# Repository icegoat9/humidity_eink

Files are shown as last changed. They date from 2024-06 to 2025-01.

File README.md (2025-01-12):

## Humidity Monitor: Feather + E Ink

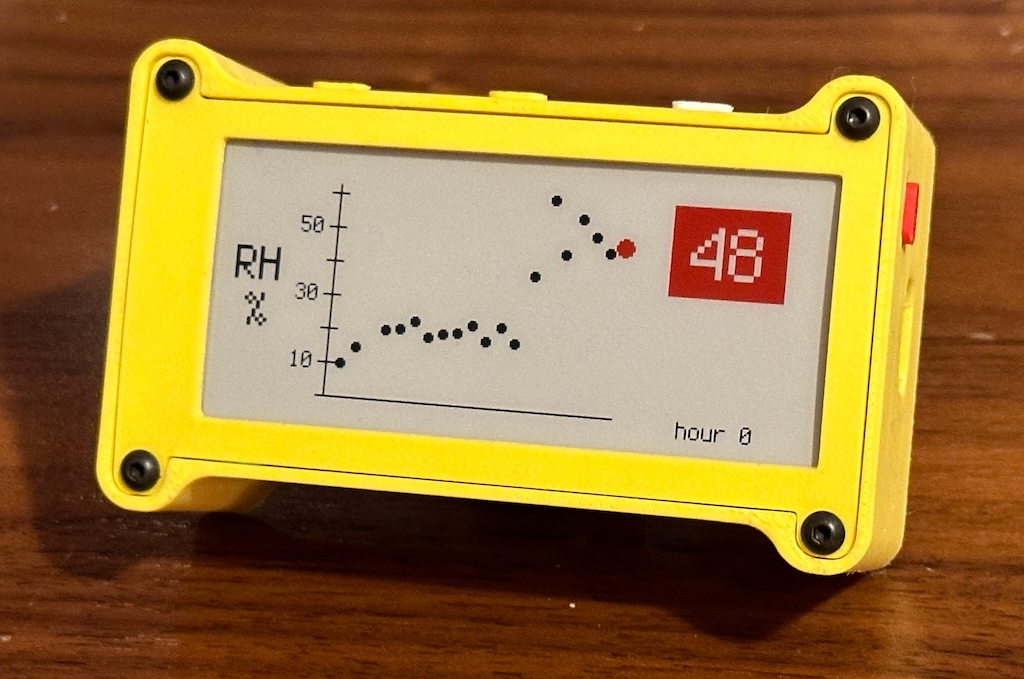
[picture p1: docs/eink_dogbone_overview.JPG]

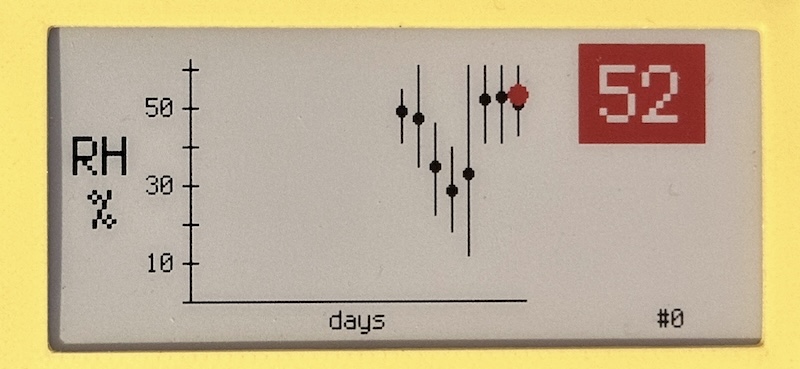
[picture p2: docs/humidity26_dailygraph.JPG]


## Overview

A humidity monitor and logger, using an E Ink display to show the recent and historical humidity with almost zero power draw (the embedded system stays in sleep mode, just waking up once an hour to read a sensor and update the display).

This was a very quick project (3 evenings, ~12 hours not counting this writeup). 

## Background

I recently picked up a 3D printer for my 'home lab', partly to make it faster to build cases for various electronics projects I work on.

I plan to store my extra printer filament in a dry box with desiccant, and wanted to throw a humidity monitor into the box-- instead of buying one, maybe I should make one (and this would be an excuse to try quick iterations on case design).

I had other projects to work on, so I told myself "If I can build a working prototype in one evening with parts I have around, I'll let myself spend a few more days polishing it."

I rarely document one-off projects like this, but I thought it would be useful/fun for when I look back at it in the future, so I took photos and screenshots along the way to let me reconstruct the process after the fact.

## Development Log

### Day 1 -- Working Prototype

Notebook sketch concept:
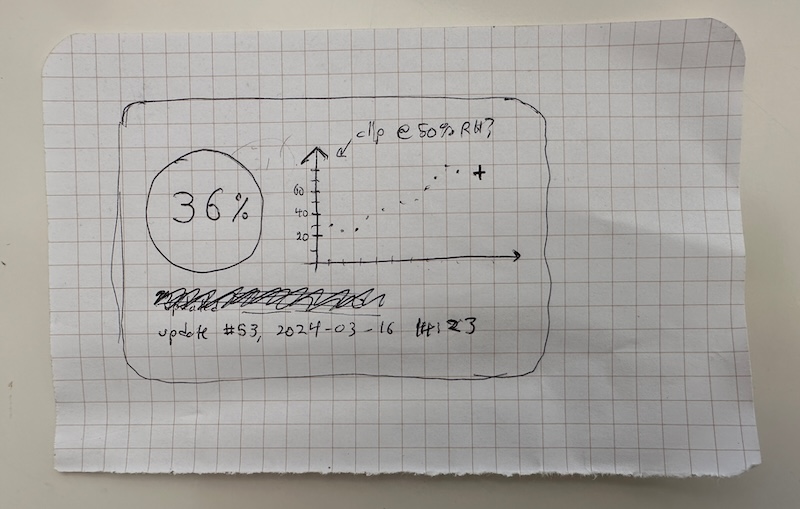
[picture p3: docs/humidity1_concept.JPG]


Components I had kicking around the shop, including a [Feather M4 Express](https://www.adafruit.com/product/3857) with a 120 Mhz Cortex M4 SAMD51 processor, a [2.9" Tri-color E Ink display](https://www.adafruit.com/product/4778), and an [AHT20 I2C capacitive humidity sensor](http://www.aosong.com/en/products-32.html) on a [breakout board](https://www.adafruit.com/product/4566):
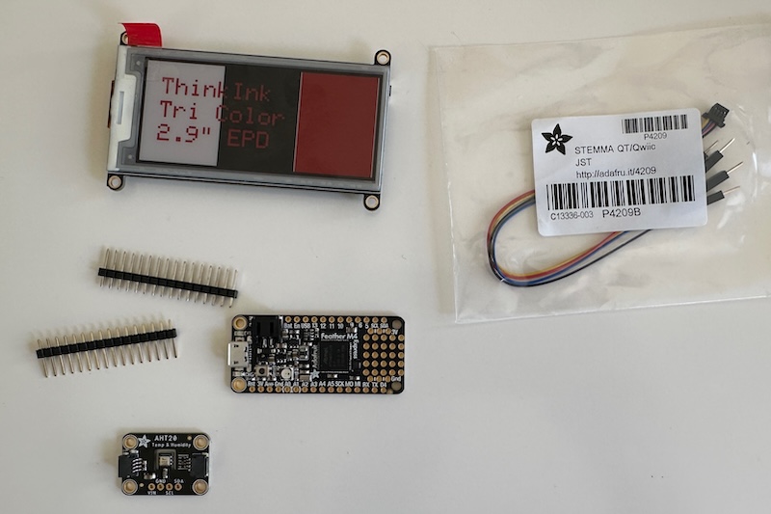
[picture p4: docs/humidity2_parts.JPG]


First I soldered headers onto the Feather PCB (tip: insert the headers into the mating display board while soldering to keep them aligned):
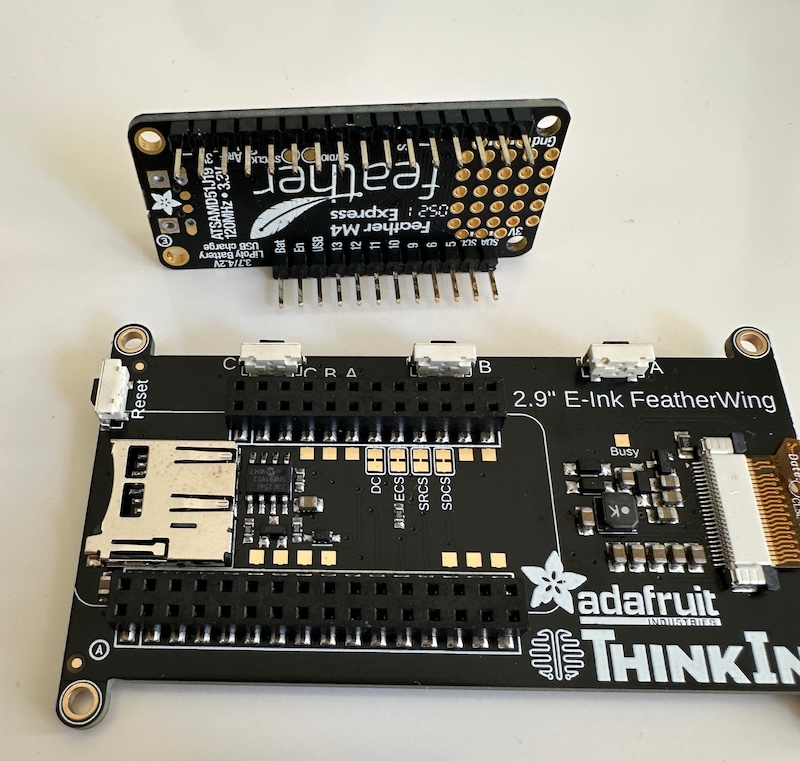
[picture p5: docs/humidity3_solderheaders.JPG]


Then I hooked up the relevant I2C bus pins to the sensor:
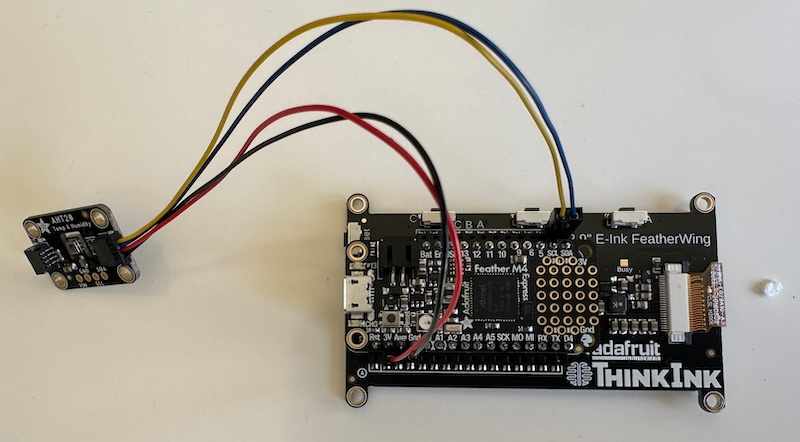
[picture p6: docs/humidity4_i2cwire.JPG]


I connected the Feather to my laptop to update the firmware and start programming, but wasn't able to communicate with it. I wasted more minutes than I want to admit before I figured out the USB cable I'd grabbed was a charging-only cable with no data connection.
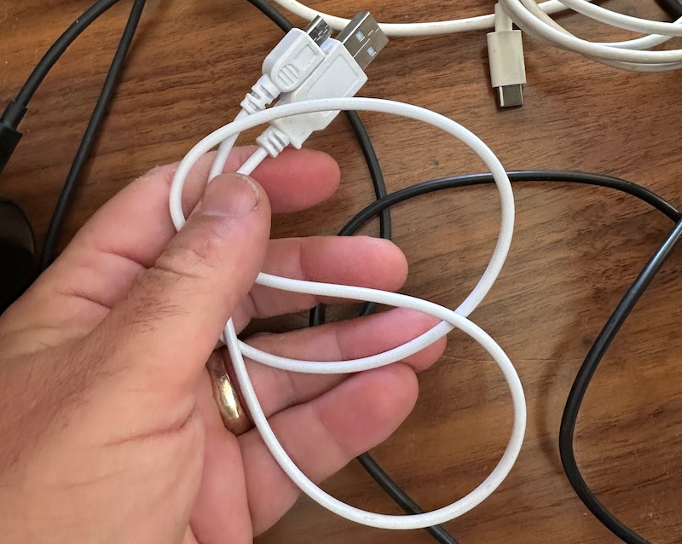
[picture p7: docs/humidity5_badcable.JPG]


Now I was able to load CircuitPython onto the device. I always start with some basic 'blink an LED' code to check my workflow:
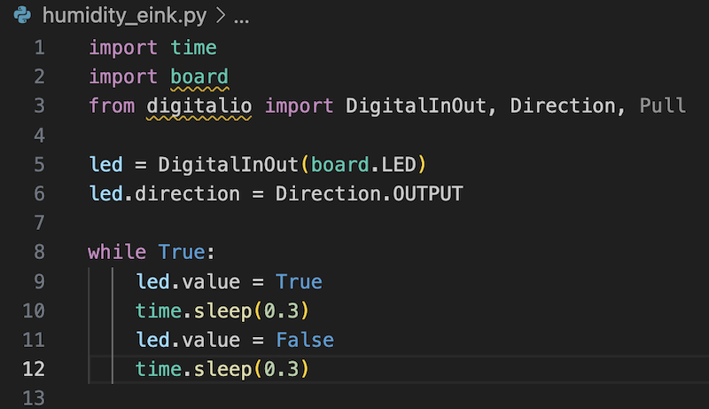
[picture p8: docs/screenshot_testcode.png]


Next, I loaded some sample code from [Adafruit's excellent-as-always documentation](https://learn.adafruit.com/adafruit-2-9-eink-display-breakouts-and-featherwings/overview), verifying I could display an image on the E Ink`.

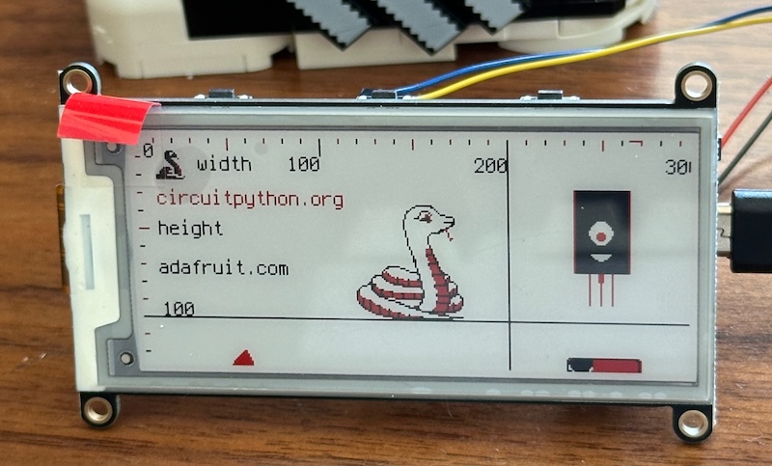
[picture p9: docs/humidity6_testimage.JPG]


I brushed up on the [`displayio`](https://docs.circuitpython.org/en/latest/shared-bindings/displayio/) library which I've used in the past to composite elements into an image and wrote a few lines of code. Oops, I forgot that (x,y) coordinates in displayio anchor by default to the vertical center of text:
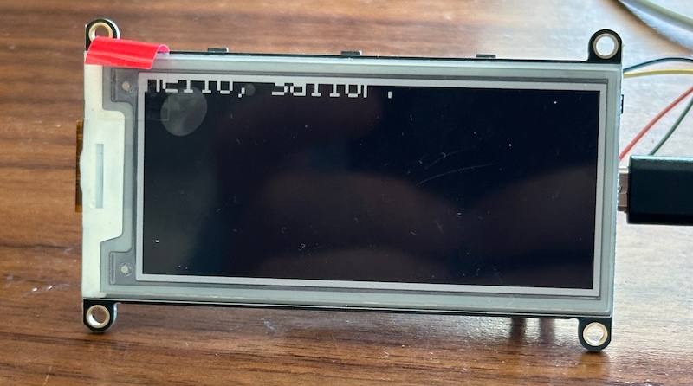
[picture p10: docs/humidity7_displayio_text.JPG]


Fixed:
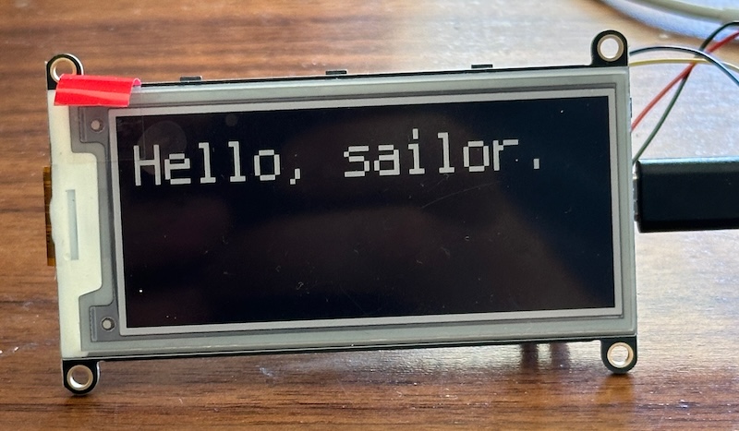
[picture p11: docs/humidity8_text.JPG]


For simple projects like this, I'm a big fan of 'printf debugging'-- just printing program status out to a serial terminal for quick feedback. I connected a terminal window to the Feather's serial-over-USB connection:
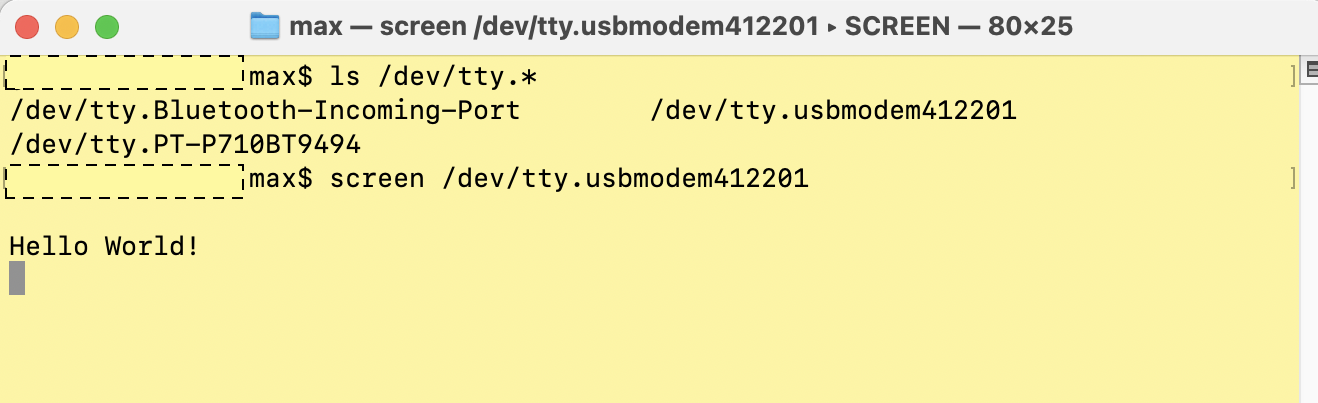
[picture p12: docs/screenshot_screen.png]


Now I wanted to communicate to the humidity sensor over I2C. One of the features of Python I love is the easy REPL / shell, allowing interactive command exploration. I read the documentation and tried out a few commands, and was able to communicate to the sensor, verifying it works the way I think and I have it wired up correctly:
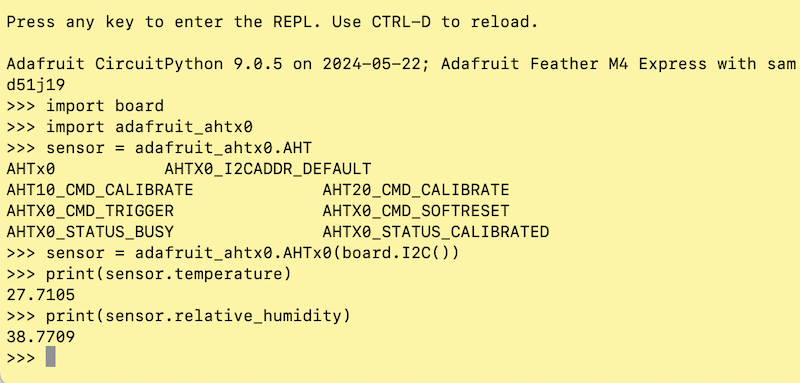
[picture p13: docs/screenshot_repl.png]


Now that I know it works, I integrated I2C code into my basic test program and displayed it:
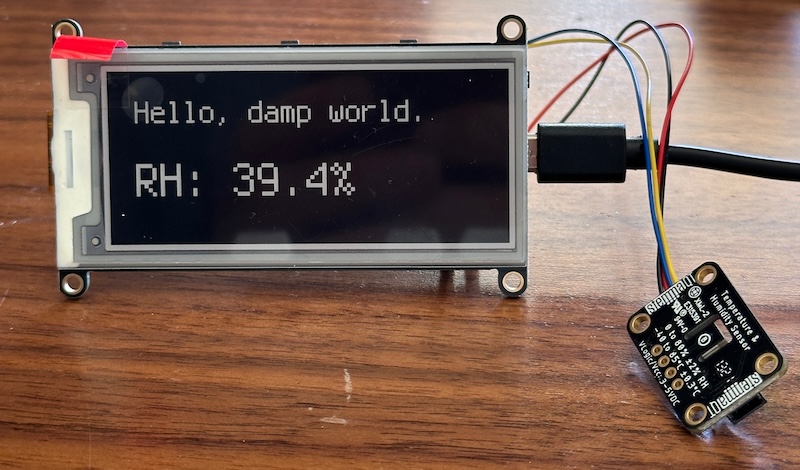
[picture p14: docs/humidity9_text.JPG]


This moment was about an hour and a half from when I had the idea and started this project. It's a key prototype milestone-- now that I know it's possible with components I have on hand, I'm excited to spend some more time on it.

I took a break to set up a git repository, back up my work in progress, and arrange my monitor windows the way I like them for more focused work. 
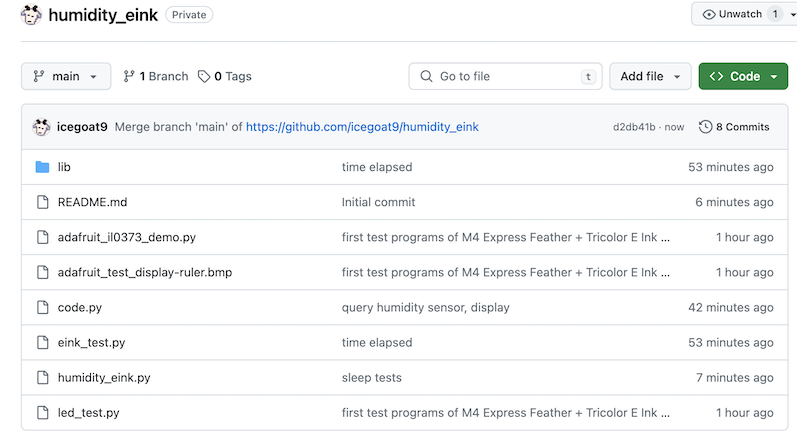
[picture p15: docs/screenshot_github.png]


Now let's dive back in.

I played around with color and formatting settings for this display (I'm only using this much slower three-color E Ink display instead of a black and white one because it's what I had on hand... but since I have it I might as well use the accent color):
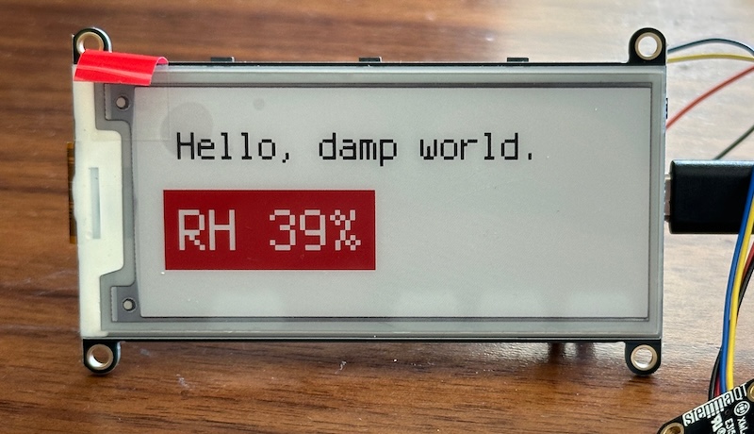
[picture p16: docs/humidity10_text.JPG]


Now I swapped in a small LiPoly battery instead of USB power, since the intent is to make this battery-powered:
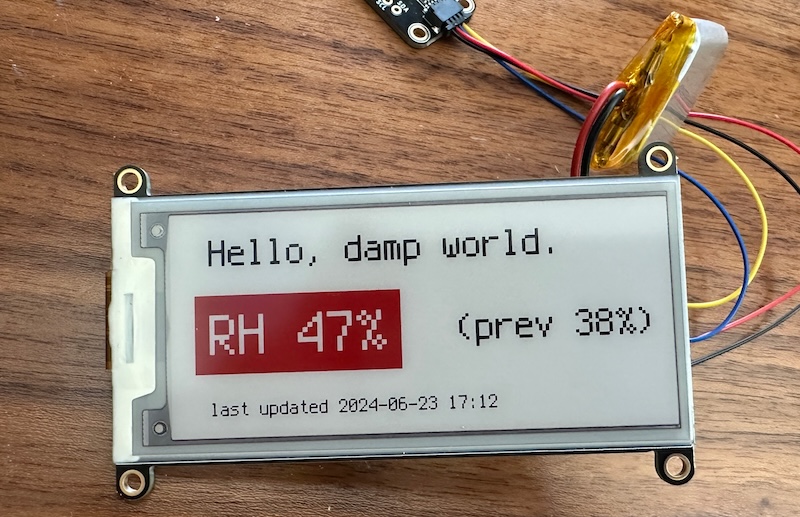
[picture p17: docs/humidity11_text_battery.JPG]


I spent a bit of time brushing up on low-power sleep modes using [`alarm.sleep`](https://learn.adafruit.com/deep-sleep-with-circuitpython/alarms-and-sleep) and wrote some test code to check I could have the system sleep and then wake itself up on some schedule. The onboard RTC time and date don't seem to persist across a sleep/wake the way I'm using it, but I don't really need an accurate time so I'll ignore that for now:
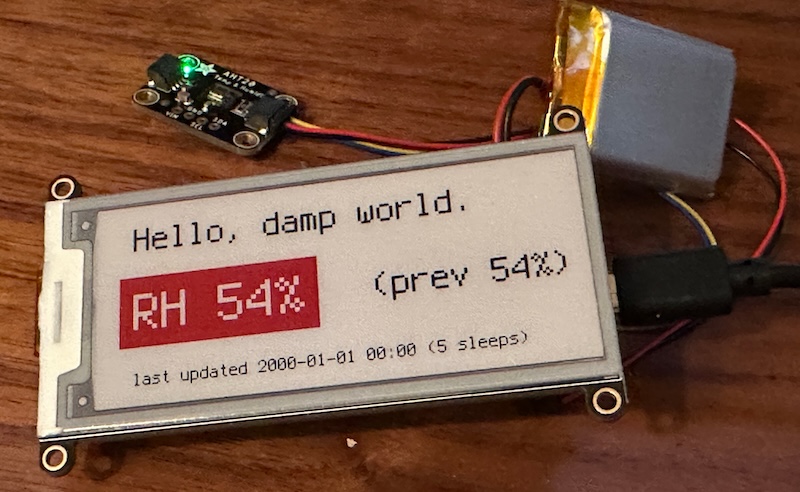
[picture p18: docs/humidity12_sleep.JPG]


There's more to do on making this look good, but let's make a case for all these loose components and wires. I'm fortunate to have a small 3D printer in my home lab, and using the PCB documentation as a starting point, in a bit over an hour I had a basic case designed and printed (about 40 minute print time with coarse draft settings):

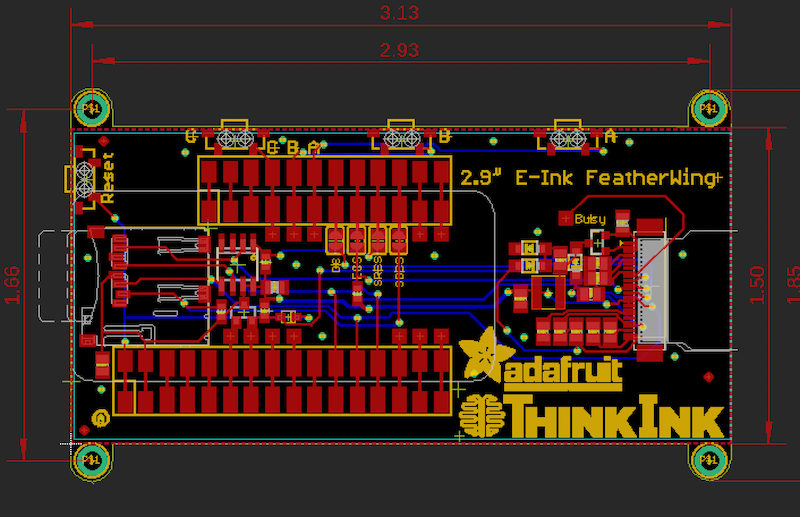
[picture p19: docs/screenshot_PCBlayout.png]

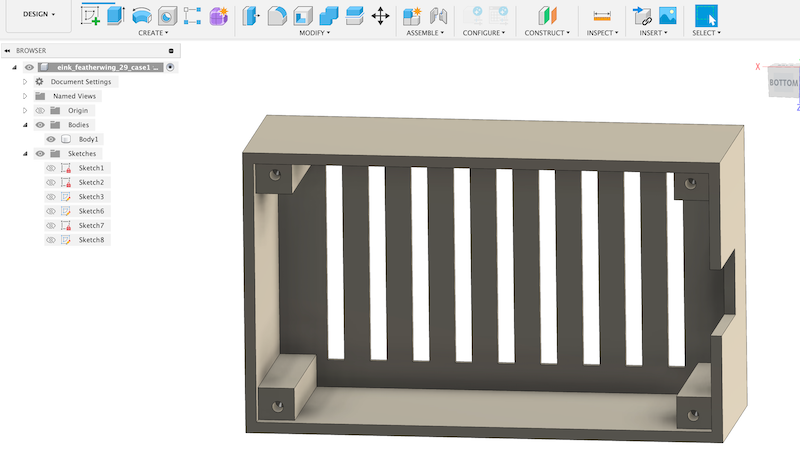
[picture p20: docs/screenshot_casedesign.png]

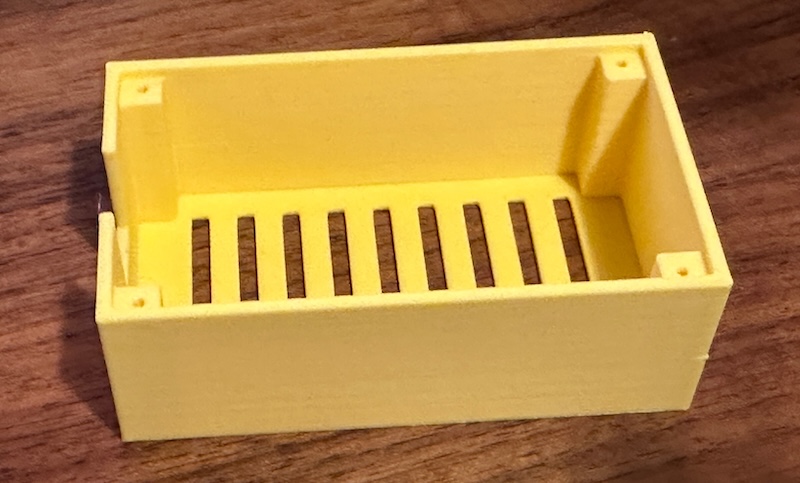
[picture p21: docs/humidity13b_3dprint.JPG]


The enclosure didn't fit perfectly (I needed slightly more PCB clearance in a few areas, but when it's this fast to design / build / test, I don't spend as much time trying to get every dimension perfect on the first try), but it worked well enough that I could dry fit the components in to it and set it inside my storage bin to imagine what it would look like:
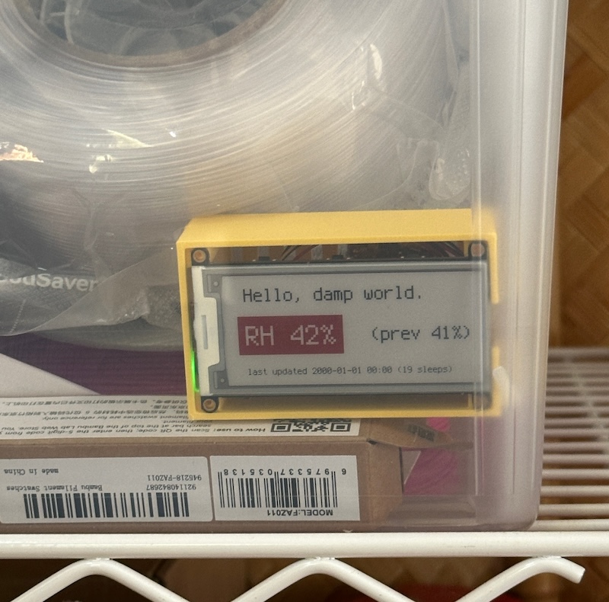
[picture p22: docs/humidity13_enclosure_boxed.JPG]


I set the system to wake up once an hour, update the display, and return to low-power sleep mode, and this is where I left it after my first evening on the project. Actually, I also fixed a few minor fit issues on the case design and set it to 3D print overnight. 

## Day 2

To some extent, this rough prototype is already 'good enough'-- I can see the humidity inside the box. But I wanted to put a few more hours of polish into it.

I went through a few more iterations of case design, fixing fit issues and adding mounting holes for the sensor.

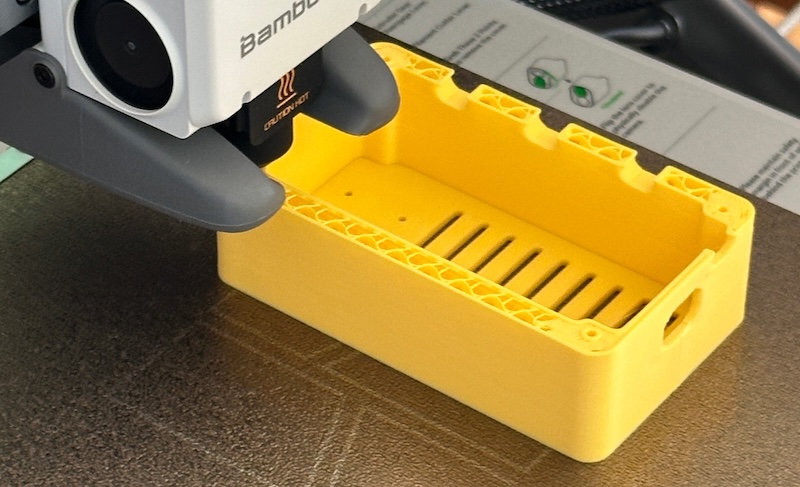
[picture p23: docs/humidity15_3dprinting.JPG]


A robust design might heat-set threaded metal inserts into the case for strong screw connections, or design in some plastic snap tabs, but for this kind of quick project I find I can usually tap threads directly into the 3D printed plastic if I'm careful and only going to open and close it a few times ever (in the 3D printer slicer I need to remember to set infill density to 100% in those areas or for the whole part, so there's material to bite into, not just a thin wall):

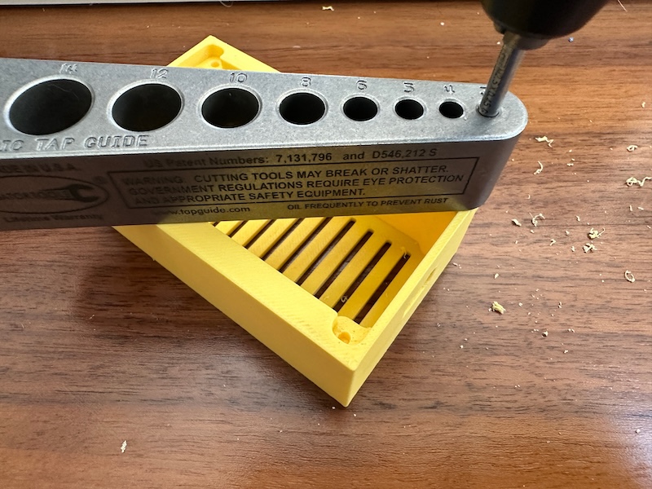
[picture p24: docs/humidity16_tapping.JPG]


Also, since I have all this display space, maybe I could do something more interesting than just print text, such as keep an internal log of humidity over time and graph it.

I tested the CircuitPython [`display_shapes`](https://docs.circuitpython.org/projects/display-shapes/en/latest/) sparkline module, but didn't love how it looked:

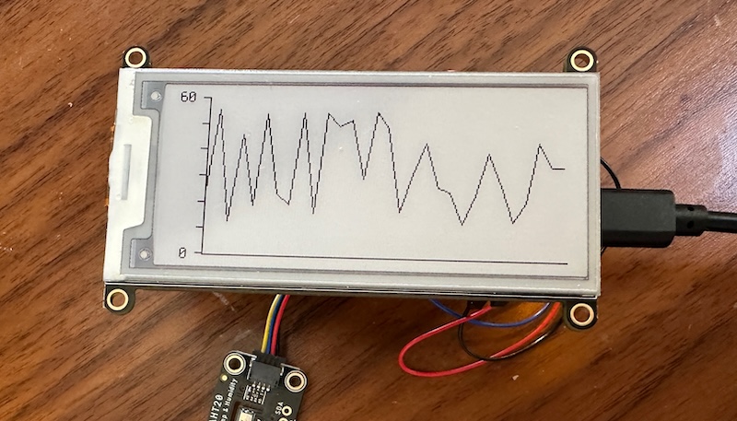
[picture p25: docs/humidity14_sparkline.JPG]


I decided to make my own chart drawing routine, using the line and circle primitives from `display_shapes`. To iterate quickly on ideas, I wrote some throwaway code using some hard-coded dummy data that just draws a set graph to the screen. After playing around with some math and settings for a while, I came up with this layout, which I liked:

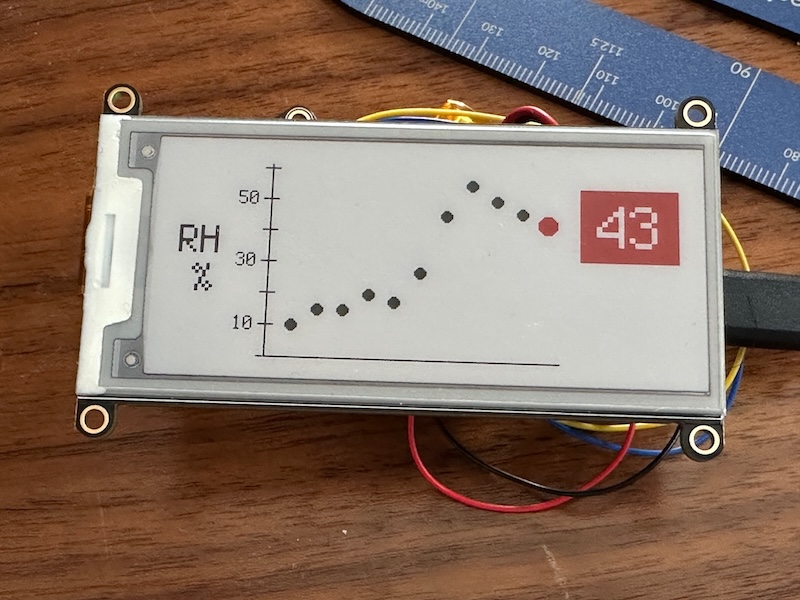
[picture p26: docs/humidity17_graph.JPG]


This was just a mockup, so I spent another hour or two cleaning up the code and building this functionality in my main program. From memory, this mostly involved:
* Setting up a circular buffer for humidity data.
* Functions to load and save data from [backup RAM / sleep memory](https://learn.adafruit.com/deep-sleep-with-circuitpython/sleep-memory)-- otherwise every time the system went into deep sleep all variables would be re-initialized. 
* Rather that re-creating the entire displayio image every time we have new data, just updating the y position of the existing data dots.

After a few tests this seemed to work as intended.

Continuing my shuffle between hardware and software, I then did one more iteration on case design, with a top sheet that frames the display more nicely:

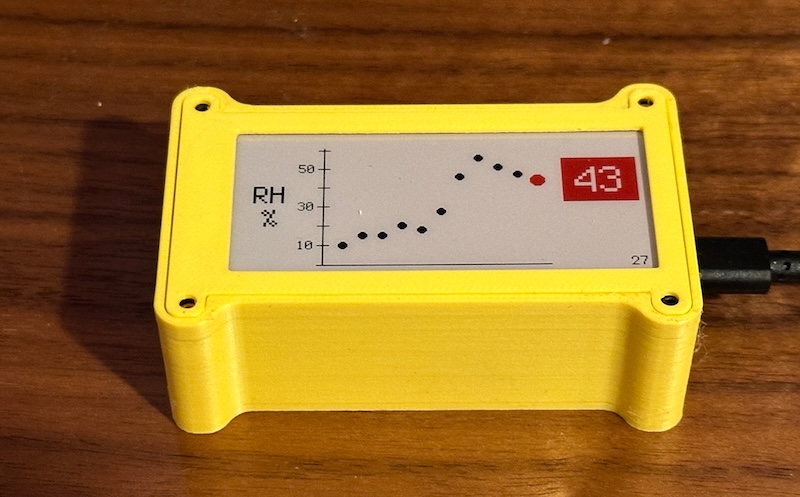
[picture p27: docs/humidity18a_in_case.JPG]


This is where I left the project at the end of about four hours of work on day two. Basically done other than putting in the screws. *Or is it...?*

### Day 3

It's *good enough* at this point, really, and I have other things to be working on, but I have time for a few final touches.

One challenge with humidity sensors in general is that many of them lose substantial accuracy outside the 20-80% RH range:

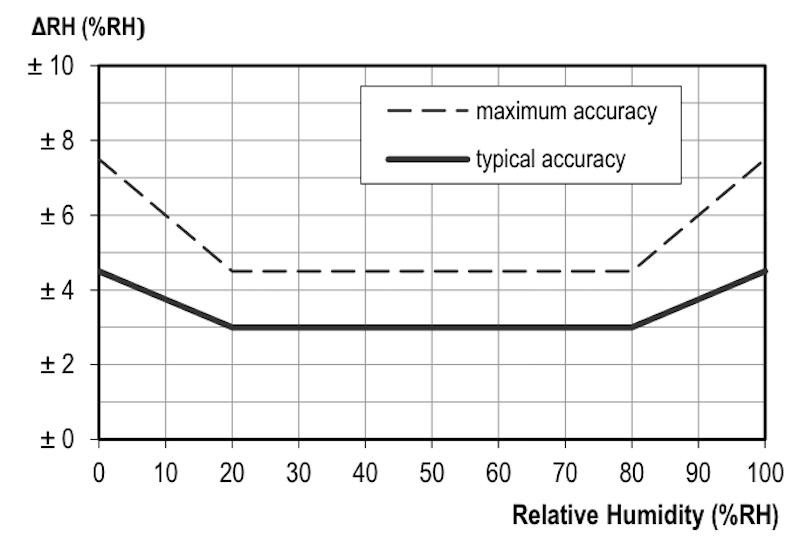
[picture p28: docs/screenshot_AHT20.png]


That may not really matter for this project (though ideally I'll be storing filament below 20% RH), but I wanted something better-- so back on Day 1 I had ordered a higher-accuracy humidity sensor, the SHT45:

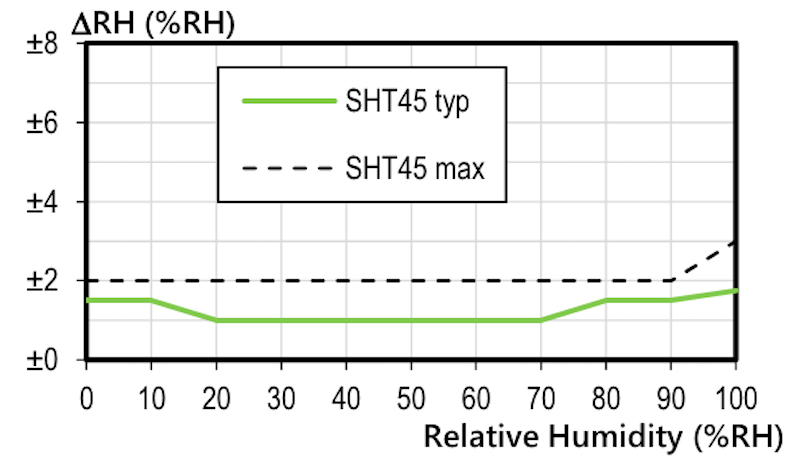
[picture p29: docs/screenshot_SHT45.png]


It arrived today (this 'Day 3' is a few days after Day 2, after a break from the project), so I swapped it in along with a few lines of changed code. Fortunately the breakout PCB it's on has the same mounting hole locations:

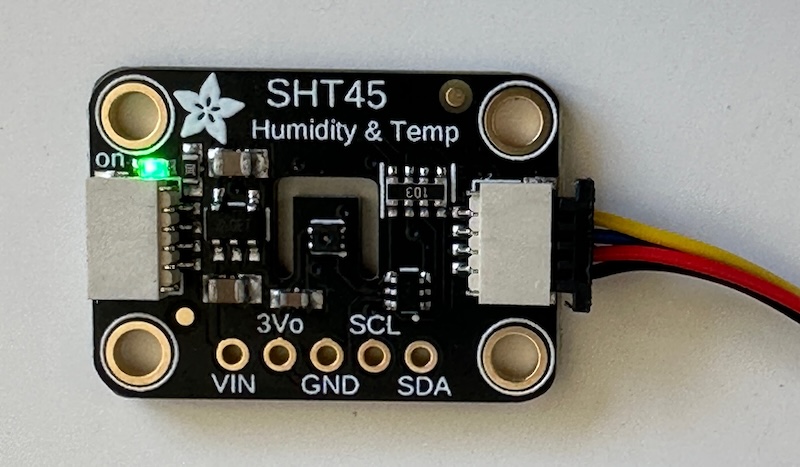
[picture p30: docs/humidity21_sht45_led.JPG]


Hmm, here's a wrinkle-- there's a constantly-on power LED on this board, which is a waste of our limited battery. I took a minute to desolder it (I wish I had a better magnifier):

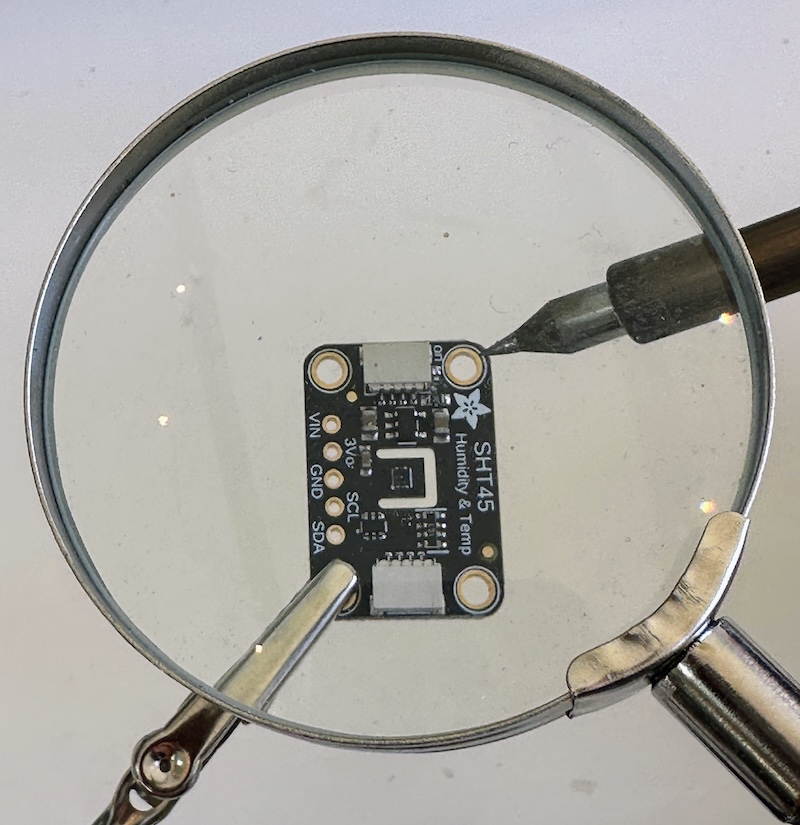
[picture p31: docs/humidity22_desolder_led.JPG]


As I prepared to assemble everything, I realized there was one more opportunity for improvement-- it would be nice to be able to press the hard reset button on the PCB without unscrewing the whole enclosure.

Maybe I should redesign the case to have a slot lined up with that button. I could even 3D print a plastic button cap to sit in the hole in the case so I don't have to poke a screwdriver into the hole to hit the button.

And if I'm adding a cutout and button... the E Ink display board I'm using has a few pushbuttons on its PCB which connect to pins on the processor. I'm not using them for anything currently, but maybe in the future they could toggle between different graphs and displays (temperature, etc), so if I might as well make them accessible as well...

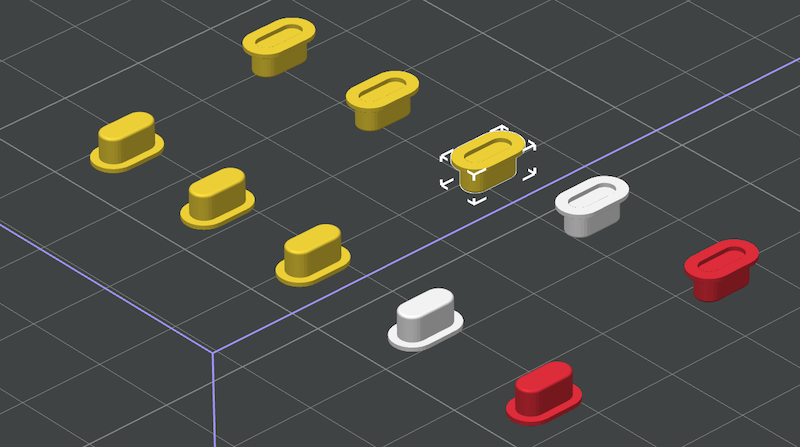
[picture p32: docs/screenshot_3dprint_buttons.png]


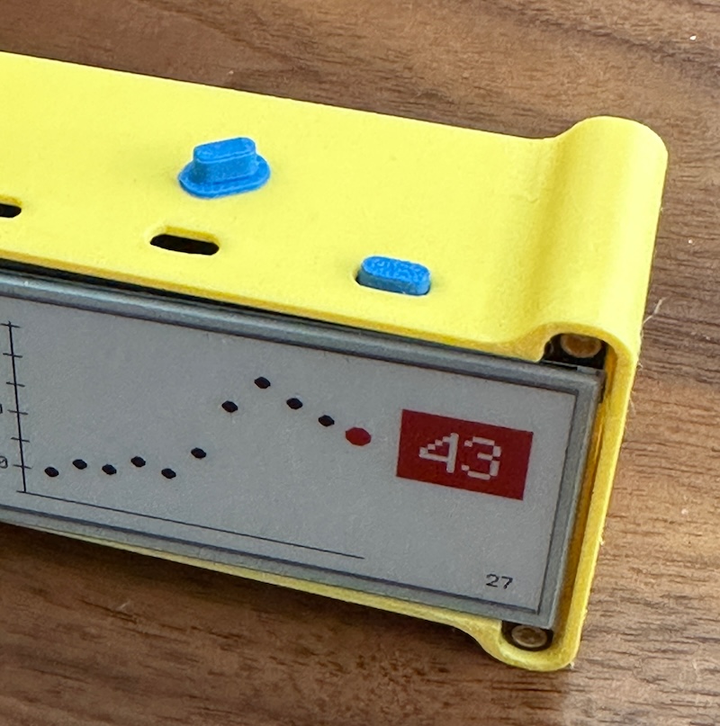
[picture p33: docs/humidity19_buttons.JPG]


Okay, time for the final assembly push.

Let's hot-glue a few jumper wires in place so they don't slide loose (if this were a real product, I'd build a custom cable with a locking connector or a custom PCB, but this is just a one-off and I'm trying to move fast):

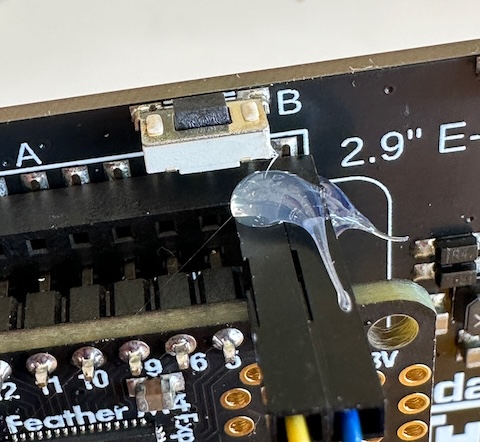
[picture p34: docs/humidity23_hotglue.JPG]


I tapped all the holes, screwed down the sensor board, staged all the buttons in their slots, and used a piece of tape to hold them in place (reminder to self: before I did this, I had many frustrating assembly attempts where one button would fall out of its hole into the case just as I slid the PCB in place):

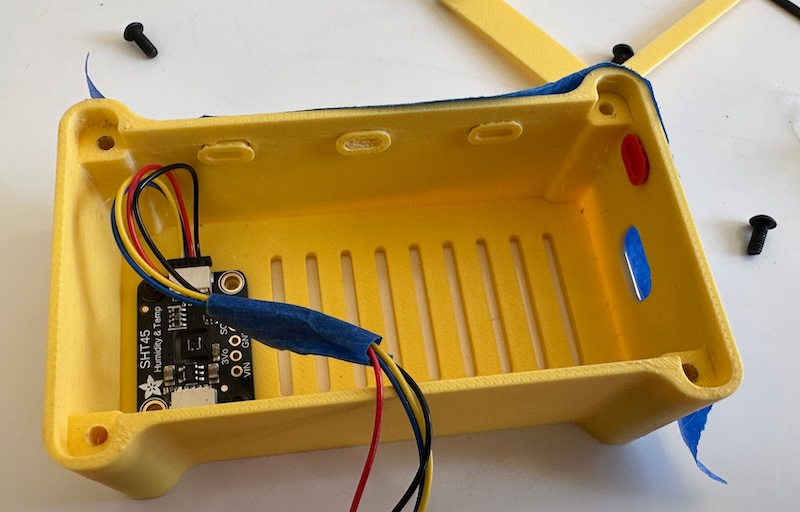
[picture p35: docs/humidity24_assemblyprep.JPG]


And... the final result!

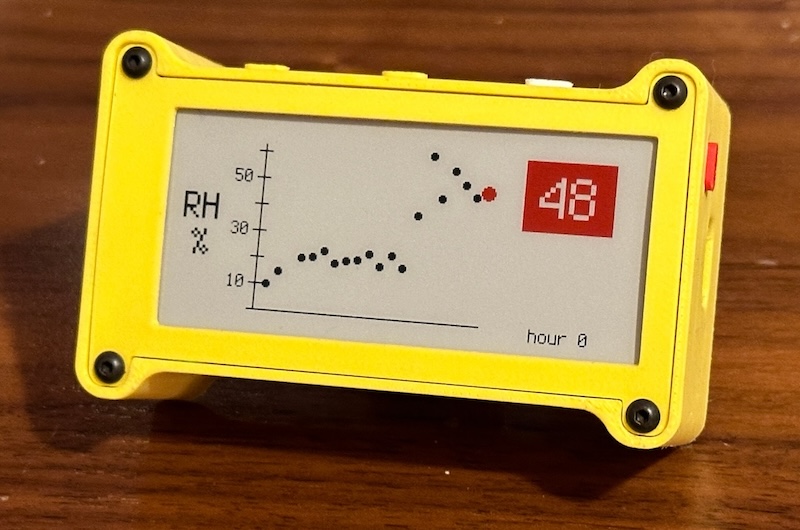
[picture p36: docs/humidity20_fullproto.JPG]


Now it's tucked away in the box of filament, logging data.

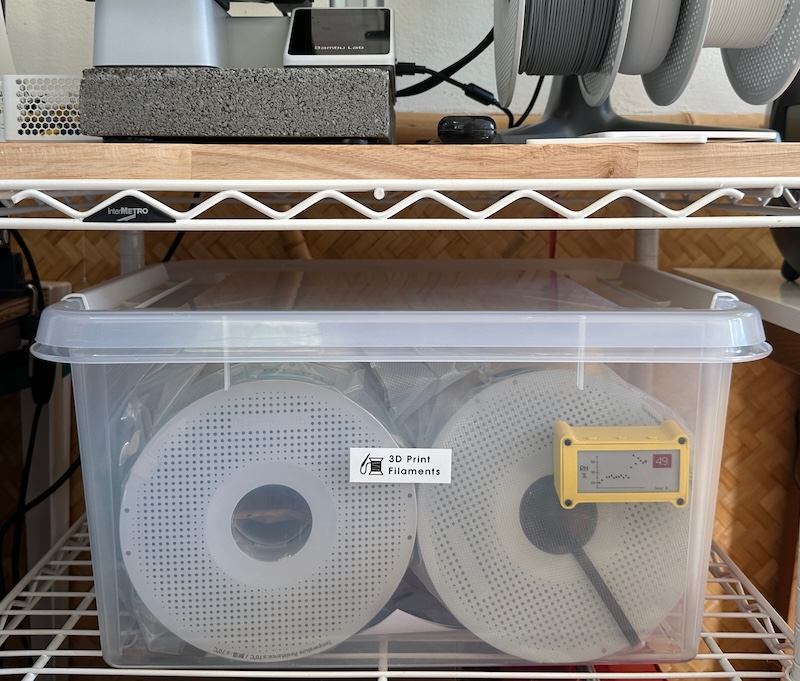
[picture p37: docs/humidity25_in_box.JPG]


### Time Invested

By looking back at some notes and the timestamps on photos and screenshots I took along the way, it looks like I spent about 12 hours on this project spread over three days.

## Updates

**December 2024:**

Spent ~2 hours updating the software to store the last ~19 days of data rather than last 20 hours, and display it grouped by day with daily min, max, and average values:



*Note: a number of these images show large RH% values, because I was initially testing on my desk or n a box without a gasket around the lid, but once I moved to a new box and added fresh dessicant, I seem to be keeping the enclosure at ~15% RH which should be good enough-- I just haven't taken new photos.*

## Future Ideas

I'm calling this done for now to catch up on other work, but I have a few ideas for future extensions:

* ~~Instead of just buffering the last 24 hours of readings in backup RAM, buffer weeks or months of readings, and change the graph to a box plot (one box per day for the past month)~~
  * Log humidity to our tiny 2MB flash memory for storage even after a reset or the battery runs down
* Dig into why the internal RTC resets on deep sleep-- maybe add an external I2C RTC with a tiny coin cell battery backup
* Measure actual power draw in various states and estimate battery life-- if needed, look into other power reduction methods (I haven't used sleep modes on this particular processor before and haven't looked under the hood into what the Python abstractions actually do in light vs. deep sleep modes relative to the processor low-level features)
  * Update: this first prototype seems to run for about three weeks / 450 screen refreshes between charges, which is less than expected (I've build some similar-scale battery-powered systems using different processers that run 3-6 months between charges), so I need to dig into the details of the deep sleep mode as well as any peripherals with background power draw 
* Integrate the buttons on the top of the case to provide some new functionality such as:
  * Switch between multiple display formats (large humidity number, graph, humidity and temperature, and so on)
  * Wake the sensor from sleep and take an immediate reading (likely not possible on this system as built, because these particular pins don't appear to have external hardware interrupts, but possible if I rewired it or switched to an ESP32 Feather)
* Revise the case design to remove the visible seam on the faceplate

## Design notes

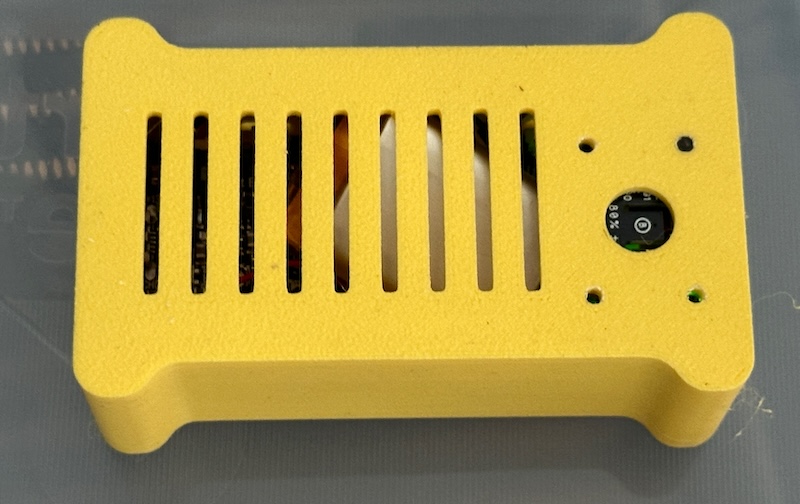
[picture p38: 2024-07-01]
docs/humidity18b_caserear.JPG

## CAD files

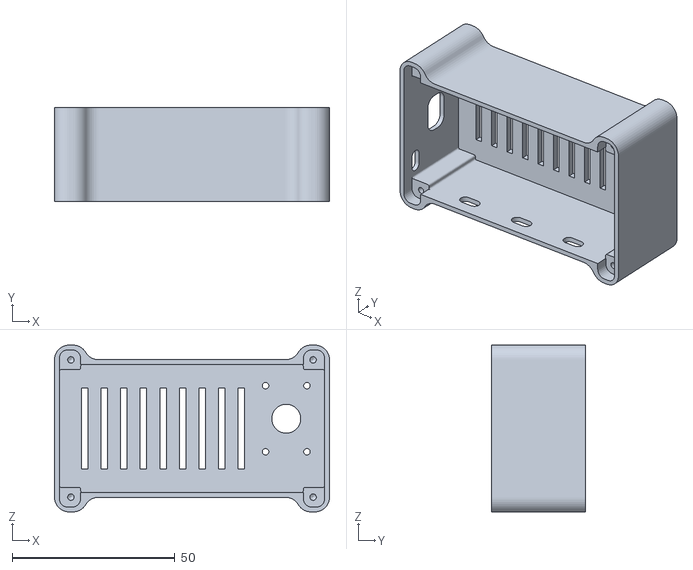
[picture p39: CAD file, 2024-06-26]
enclosure/eink29_feather_case_bottom_v16.stl
84.5 x 29.0 x 51.3

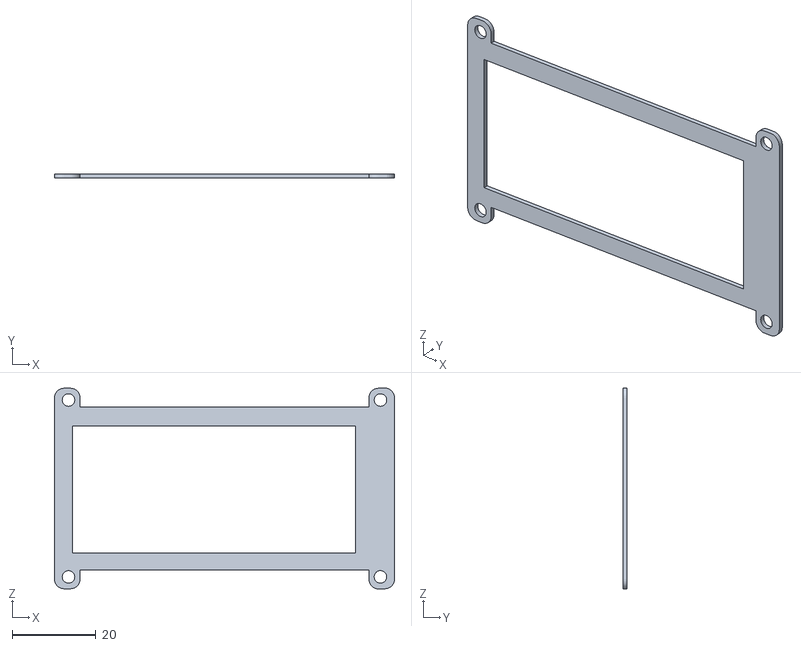
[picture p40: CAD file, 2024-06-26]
enclosure/eink29_feather_case_top_v18.stl
81.1 x 1.00 x 47.9

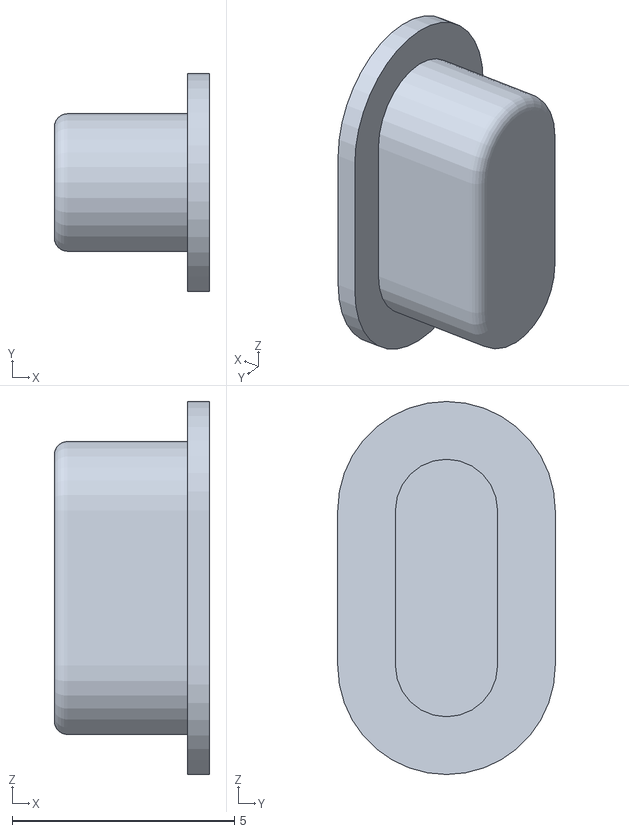
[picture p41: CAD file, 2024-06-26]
enclosure/case_button_v2.stl
3.50 x 4.90 x 8.40

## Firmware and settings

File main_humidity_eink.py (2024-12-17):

"""
Read relative humdity from I2C sensor, display on E Ink screen.

Additionally, display graph of RH over time, and deep sleep for long runtime on battery.
"""

import time
import board
import displayio
import fourwire
import adafruit_il0373
import terminalio
import random
from adafruit_display_text import label
from adafruit_display_shapes.line import Line
from adafruit_display_shapes.circle import Circle

# import adafruit_ahtx0   # previously, lower-accuracy humidity sensor
import adafruit_sht4x
import alarm
import digitalio

# Featherwing pushbutton pin assignment (currently unused)
# note: may vary by Feather but below is true for Feather M4 Express
pin_button_C = board.D13
pin_button_B = board.D12
pin_button_A = board.D11

# In debug mode, add some random noise to data, generate a lot of additional data each update, update the screen more often, and other additions for testing
DEBUG_MODE = False

# color and font constants
BLACK = 0x000000
WHITE = 0xFFFFFF
RED = 0xFF0000
FONT = terminalio.FONT

# Initialize I2C connection to humidity sensor
rh_sensor = adafruit_sht4x.SHT4x(board.I2C())

# initialize a fixed-length RH buffer and related variables
# note: these variables may be overwritten below from Sleep Memory if we are resuming after a deep sleep
rh_data = [0] * (12 * 19)  # 19 days worth of data
rh_data_index = 0
run_cycles = 0
SLEEP_MINUTES = 120
data_per_box = 24 * 60 // SLEEP_MINUTES  # how many data points per box (often meaning, per day)
if DEBUG_MODE:
    SLEEP_MINUTES = 3  # Warning: do not update the tricolor E Ink screen more often than every three minutes


def save_to_sleep_memory():
    alarm.sleep_memory[0] = rh_data_index
    # sleep memory can only hold bytes-- the below will allow counting 2^16 run_cycles rather than 2^8
    # (and then will wrap around, though the battery won't last even close to 2^16 cycles)
    alarm.sleep_memory[1] = (run_cycles // 256) % 256
    alarm.sleep_memory[2] = run_cycles % 256
    for i in range(len(rh_data)):
        alarm.sleep_memory[i + 3] = rh_data[i]


def load_from_sleep_memory():
    global rh_data
    global rh_data_index
    global run_cycles
    rh_data_index = alarm.sleep_memory[0]
    run_cycles = alarm.sleep_memory[1] * 256 + alarm.sleep_memory[2]
    for i in range(len(rh_data)):
        rh_data[i] = alarm.sleep_memory[i + 3]


# Initialize data depending on bootup vs. waking from deep sleep
if not alarm.wake_alarm:
    print("**********************************")
    print("first boot, initializing variables")
    run_cycles = 0
    rh_data_index = 0
    print(f"Initializing data buffer with {len(rh_data)} slots...")
    if DEBUG_MODE:
        # seed with initial temporary dummy data
        DUMMY_BOXES = 4
        for b in range(DUMMY_BOXES):
            for i in range(data_per_box):
                rh_data[b * data_per_box + i] = 50 - 10 * b + random.randint(-10, 10)
        rh_data_index = DUMMY_BOXES * data_per_box - 1
else:
    print("waking after deep sleep, loading variables from sleep memory")
    load_from_sleep_memory()
if DEBUG_MODE:
    print("DEBUG MODE ON -- randomized data generation")


### Display initialization

# Used to ensure the display is free in CircuitPython
displayio.release_displays()

# Define the pins needed for display use, create displayio connection
spi = board.SPI()
epd_cs = board.D9
epd_dc = board.D10
epd_reset = None
epd_busy = None
display_bus = fourwire.FourWire(spi, command=epd_dc, chip_select=epd_cs, reset=epd_reset, baudrate=1000000)
time.sleep(1)  # Wait a bit

# Create the display object
display = adafruit_il0373.IL0373(
    display_bus,
    width=296,
    height=128,
    rotation=270,
    busy_pin=epd_busy,
    highlight_color=RED,
)

# Create a display group for our screen objects
display_group = displayio.Group()

#############################
### Lay out display content

# white background
canvas = displayio.Bitmap(display.width, display.height, 1)
background_palette = displayio.Palette(1)
background_palette[0] = WHITE
background = displayio.TileGrid(canvas, pixel_shader=background_palette, x=0, y=0)
display_group.append(background)

# chart layout constants
graph_y0 = 110
graph_x0 = 54
data_x0 = 4
marker_size = 2
highlight_marker_size = 4
px_per_sample = 10
graph_width = 140
graph_height = 100
rh_max = 60
py_per_rh = graph_height / rh_max
yticks = rh_max // 10
tick_halfwidth = 3
py_tick = graph_height // yticks
px_tick = graph_width // (len(rh_data) // data_per_box)

# Draw graph axes and labels
graph = displayio.Group()

xaxis_line = Line(graph_x0, graph_y0, graph_x0 + graph_width, graph_y0, color=BLACK)
yaxis_line = Line(graph_x0, graph_y0, graph_x0, graph_y0 - graph_height, color=BLACK)
graph.append(xaxis_line)
graph.append(yaxis_line)

yaxis_labels = displayio.Group(scale=2, x=6, y=graph_y0 - (graph_height // 2) - 10)
yaxis_labels.append(label.Label(font=FONT, text="RH", color=BLACK))
yaxis_labels.append(label.Label(x=3, y=11, font=FONT, text="%", color=BLACK))
graph.append(yaxis_labels)

xaxis_label = label.Label(
    x=graph_x0 + graph_width // 2 - 12, y=display.height - 10, font=FONT, text="days", color=BLACK
)
graph.append(xaxis_label)

# special runtime # in corner
runtime_text = displayio.Group(scale=1, x=display.width - 46, y=display.height - 10)
runtime_text.append(label.Label(FONT, text=f"#{run_cycles}", color=BLACK))
display_group.append(runtime_text)


# Draw graph ticks
yticks_group = displayio.Group()
for i in range(yticks + 1):
    yticks_group.append(
        Line(
            graph_x0 - tick_halfwidth,
            graph_y0 - i * py_tick,
            graph_x0 + tick_halfwidth,
            graph_y0 - i * py_tick,
            color=BLACK,
        )
    )
    if (i % 2) == 1:
        yticks_group.append(
            label.Label(x=graph_x0 - 18, y=graph_y0 - i * py_tick, font=FONT, text=str(i * 10), color=BLACK)
        )
graph.append(yticks_group)

# Set up graph object (initially empty)
data_group = displayio.Group()
graph.append(data_group)
data_group_index = graph.index(data_group)

current_rh_text = displayio.Group(scale=3, x=display.width - 70, y=graph_y0)
current_rh_text.append(
    label.Label(
        FONT,
        text="00",
        color=WHITE,
        background_color=RED,
        padding_left=3,
        padding_right=3,
        padding_top=1,
        padding_bottom=1,
    )
)
graph.append(current_rh_text)

# Place the display group on the screen
display_group.append(graph)
display.root_group = display_group


## functions to update graph and current_rh_text with actual data
def update_rh_data():
    global rh_data
    global rh_data_index
    current_rh = rh_sensor.relative_humidity
    if DEBUG_MODE:
        current_rh += random.randint(-10, 10)
    rh_data_index = (rh_data_index + 1) % len(rh_data)
    print(f"humidity = {current_rh}%, saving to slot {rh_data_index} in data buffer")
    rh_data[rh_data_index] = int(current_rh + 0.5)  # round


def mean(list):
    return sum(list) / len(list)


def remove_zeros(lst):
    return [x for x in lst if x != 0]


def min_nonzero(lst):
    """Return smallest non-zero element in list, or 0 if empty list"""
    lst = remove_zeros(lst)
    if len(lst) == 0:
        return 0
    else:
        return min(lst)


def mean_nonzero(lst):
    """Return average non-zero element in list, or 0 if empty list"""
    lst = remove_zeros(lst)
    if len(lst) == 0:
        return 0
    else:
        return mean(lst)


def scale_and_clip(rh):
    """Convert RH data into pixel Y position, with some clipping safety checks."""
    d = min(rh_max, max(rh, 0))
    dy = int(d * py_per_rh)
    return dy


def wrapped_slice(lst, i0, width):
    """Return a width slice from lst as a circular buffer, wrapping around if needed"""
    i0 = i0 % len(lst)
    if width > len(lst):
        return lst
    if i0 + width <= len(lst):
        return lst[i0 : i0 + width]  # normal slice
    else:
        a = lst[i0:]
        wrap = i0 + width - len(lst)
        b = lst[:wrap]
        return a + b


def update_graph():
    """Update graph (overwriting data_group object) with data pulled from global rh_data buffer."""
    data_group = displayio.Group()
    num_boxes = (len(rh_data) - 1) // data_per_box + 1
    for b in range(num_boxes):
        # extract subset of data for this box, starting with oldest data
        boxdata = wrapped_slice(rh_data, rh_data_index + 1 + b * data_per_box, data_per_box)
        dmin_y = scale_and_clip(min_nonzero(boxdata))
        dmax_y = scale_and_clip(max(boxdata))
        davg_y = scale_and_clip(mean_nonzero(boxdata))
        x = graph_x0 + data_x0 + (b + 1) * px_tick
        if davg_y != 0:
            # if bin has data
            data_group.append(Line(x0=x, y0=graph_y0 - dmin_y, x1=x, y1=graph_y0 - dmax_y, color=BLACK))
            data_group.append(Circle(x, graph_y0 - davg_y, r=marker_size, fill=BLACK, outline=None))
    # add most recent data
    drecent_y = scale_and_clip(rh_data[rh_data_index])
    data_group.append(Circle(x, graph_y0 - drecent_y, r=highlight_marker_size, fill=RED, outline=None))
    # replace past data_group object
    graph.pop(data_group_index)
    graph.insert(data_group_index, data_group)
    # update current RH values
    current_rh_text[0].text = f"{rh_data[rh_data_index]}"
    rh_y = graph_y0 - int(rh_data[rh_data_index] * py_per_rh)
    rh_y = min(100, max(20, rh_y))
    current_rh_text.y = rh_y


while True:
    # update RH and graph with current reading
    update_rh_data()
    if DEBUG_MODE:
        # generate a lot of additional data
        for i in range(40):
            update_rh_data()
    update_graph()
    run_cycles += 1
    # actually update E Ink screen
    display.refresh()
    ## deep sleep until next update period
    time_alarm = alarm.time.TimeAlarm(monotonic_time=time.monotonic() + 60 * SLEEP_MINUTES)
    print(f"entering deep sleep for {SLEEP_MINUTES} minutes, saving critical data to sleep memory...")
    save_to_sleep_memory()
    alarm.exit_and_deep_sleep_until_alarms(time_alarm)
    print("ERROR: deep sleep failed, reached unexpected location in code...")

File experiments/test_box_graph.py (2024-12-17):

# Test drawing what was initially conceived as a box-and-whisker plot for each day's data,
#  though in prototyping evolved to a simpler plot with just a line to show min/max values
#  for the day and a circle to mark the mean, so this test program is slightly misnamed.

import time
import board
import displayio
import fourwire
import adafruit_il0373
import terminalio
from adafruit_display_text import label
import adafruit_display_shapes
from adafruit_display_shapes.line import Line
from adafruit_display_shapes.circle import Circle

print("running test_box_graph.py")

# Used to ensure the display is free in CircuitPython
displayio.release_displays()

# Define the pins needed for display use, create displayio connection
spi = board.SPI()
epd_cs = board.D9
epd_dc = board.D10
epd_reset = None
epd_busy = None
display_bus = fourwire.FourWire(spi, command=epd_dc, chip_select=epd_cs, reset=epd_reset, baudrate=1000000)
time.sleep(1)  # Wait a bit

# color constants
BLACK = 0x000000
WHITE = 0xFFFFFF
RED = 0xFF0000

# Create the display object - the third color is red (0xff0000)
display = adafruit_il0373.IL0373(
    display_bus,
    width=296,
    height=128,
    rotation=270,
    busy_pin=epd_busy,
    highlight_color=RED,
)

# Create a display group for our screen objects
display_group = displayio.Group()

# white background (TBD if simpler way to do this)
canvas = displayio.Bitmap(display.width, display.height, 1)
background_palette = displayio.Palette(1)
background_palette[0] = WHITE  # White
background = displayio.TileGrid(canvas, pixel_shader=background_palette, x=0, y=0)
display_group.append(background)

# dummy data for graph
data = [5, 7, 13, 23, 16, 10, 19, 20, 13, 18, 17, 6, 20, 15, 22, 20, 21, 23, 19, 20, 21, 23, 19, 23, 19, 38, 78, 45, 55, 50, 46, 41]
data_per_box = 12  # how many data points per box (often meaning, per day)

# graph layout constants
graph_y0 = 115
graph_x0 = 54
marker_size = 2
highlight_marker_size = 4
px_per_sample = 10
graph_width = 140
graph_height = 100
rh_max = 60
py_per_rh = graph_height / rh_max
tick_halfwidth = 3
yticks = rh_max // 10
py_tick = graph_height // yticks
px_tick = graph_width // len(data)

# Draw graph axes and labels
graph = displayio.Group()

xaxis_line = Line(graph_x0, graph_y0, graph_x0 + graph_width, graph_y0, color=BLACK)
yaxis_line = Line(graph_x0, graph_y0, graph_x0, graph_y0 - graph_height, color=BLACK)
graph.append(xaxis_line)
graph.append(yaxis_line)

axis_labels = displayio.Group(scale=2, x=6, y=graph_y0 - (graph_height // 2) - 10)
# axis_labels.append(label.Label(x=30, y=graph_y0 + 10, font=terminalio.FONT, text="Time", color=BLACK))
axis_labels.append(label.Label(font=terminalio.FONT, text="RH", color=BLACK))
axis_labels.append(label.Label(x=3, y=11, font=terminalio.FONT, text="%", color=BLACK))
graph.append(axis_labels)

# Draw graph ticks
yticks_group = []
for i in range(yticks + 1):
    graph.append(Line(graph_x0 - tick_halfwidth, graph_y0 - i * py_tick, graph_x0 + tick_halfwidth, graph_y0 - i * py_tick, color=BLACK))
    if (i % 2) == 1:
        # tick label
        graph.append(
            label.Label(x=graph_x0 - 18, y=graph_y0 - i * py_tick, font=terminalio.FONT, text=str(i * 10), color=BLACK)
        )

def mean(list):
    return sum(list) / len(list)

data_group = displayio.Group()
graph.append(data_group)
data_group_index = graph.index(data_group)

def scale_and_clip(rh):
    """Convert RH data into pixel Y position, with some clipping safety checks."""
    d = min(rh_max, max(rh, 0))
    dy = int(d * py_per_rh)
    if dy == 0:
        dy = -100  # offset zero (invalid?) data off the screen
    return dy

def overwrite_graph(updatedata):
    """create graph data object, and replace existing display.io Group"""
    data_group = displayio.Group()
    num_boxes = (len(updatedata) - 1) // data_per_box + 1
    for b in range(num_boxes):
        # extract subset of data for this box
        boxdata = updatedata[data_per_box * b: data_per_box * (b+1)]
        # calculate (clipped-to-visible) versions of grouped data parameters
        dmin_y = scale_and_clip(min(boxdata))
        dmax_y = scale_and_clip(max(boxdata))
        davg_y = scale_and_clip(mean(boxdata))
        x = graph_x0 + 5 + (b + 1) * px_tick
        data_group.append(Line(x0 = x, y0 = graph_y0 - dmin_y, x1 = x, y1 = graph_y0  - dmax_y, color=BLACK))
        data_group.append(Circle(x, graph_y0 - davg_y, r = marker_size, fill=BLACK, outline=None))
    # add most recent data
    drecent_y = scale_and_clip(updatedata[-1])
    data_group.append(Circle(x, graph_y0 - drecent_y, r = highlight_marker_size, fill=RED, outline=None))
    # replace past data
    graph.pop(data_group_index)
    graph.insert(data_group_index, data_group)
    data_text[0].text = f"{updatedata[-1]}"

data_text = displayio.Group(scale=3, x=display.width - 67, y=graph_y0 - int(data[-1] * py_per_rh))
data_text.append(
    label.Label(
        terminalio.FONT,
        text="00",
        color=WHITE,
        background_color=RED,
        padding_left=3,
        padding_right=3,
        padding_top=1,
        padding_bottom=1,
    )
)
graph.append(data_text)

# update graph and data_text with actual data (well, dummy data)
overwrite_graph(data)

# Place the display group on the screen
display_group.append(graph)

# special runtime # in corner
data_text = displayio.Group(scale=1, x=display.width - 40, y=display.height - 10)
data_text.append(label.Label(terminalio.FONT, text="27", color=BLACK))
display_group.append(data_text)

display.root_group = display_group
display.refresh()

while True:
    # dummy data for graph
    time.sleep(180)
    newdata = [20, 21, 23, 19, 20, 21, 23, 19, 23, 19, 38, 78, 45, 55, 50, 46, 41, 35, 27, 17]
    overwrite_graph(newdata)
    display.refresh()
    quit()

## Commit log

2024-06-23 query humidity sensor, display
2024-06-24 set RTC, track time (WIP)
2024-06-26 swap in graph code to main program
    [graph_test.py]
2024-06-26 enclosure STL snapshot
    [case_button_v2.stl, eink_feather_29_case_top_v18.stl, eink_featherwing_29_case_bottom_v16.stl]
2024-06-26 organize / rename folders
    [eink29_feather_case_bottom_v16.stl, eink29_feather_case_top_v18.stl]
2024-06-28 swap in higher-accuracy SHT45 sensor
    [main_humidity_eink.py]
2024-06-28 test of waking from deep sleep using pinalarm-- but doesn't work on this particular Feather on the pins we have available
    [main_humidity_eink.py]
2024-08-03 bugfix: sleep byte memory error when run_cycles exceeded 256
    [main_humidity_eink.py]
2024-12-16 prototype aggregated-per-day graph layout
